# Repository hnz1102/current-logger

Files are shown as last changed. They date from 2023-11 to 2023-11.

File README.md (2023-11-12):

<div align="center">
  <h1><code>Voltage-Current Logger</code></h1>
  <p>
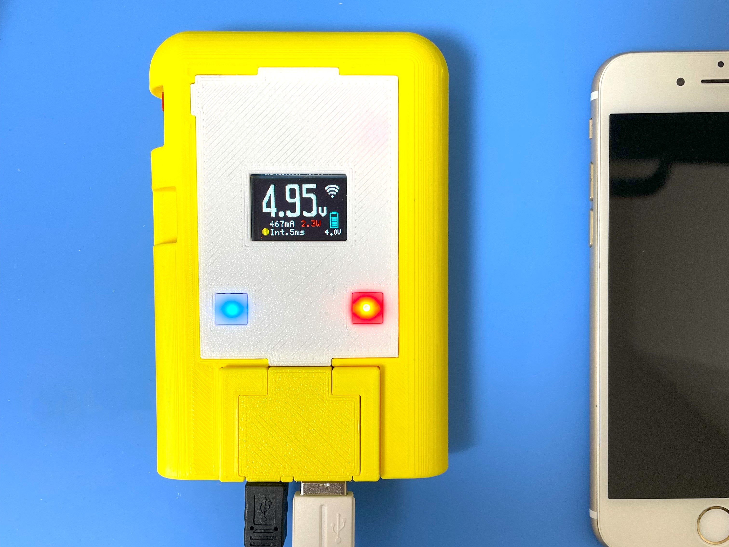
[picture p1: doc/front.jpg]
    
  </p>
</div>

# Voltage-Current Logger - High-resolution digital power monitor and logger

This tool provides a logging function that gets data on voltage, current and power consumption. Voltage input range is from 0 to 85V, Maximum current input is 15A. 

# Feature

**High-resolution** - By using Texas Instruments INA228 IC - 20-bit delta-sigma ADC, It can be got measurement data with 195.uV Bus voltage and 163.84mV Shunt voltage. 

**Microcontroller on board** - No need for a client PC when you are measuring. Directly send to the server. 

**Transfer measurement data via WiFi** - This Logger can transfer data to Linux PC via WiFi network and you can see the dashboard graph in influxDB.

**Battery Powered** - Using LiPo battery. It can run for 24-48 hours.

**Multiple Adopter** - This Logger can be changed 4 type adopters (USB-Type-C-Type-C, USB-Type-A-mini Type-B, JST-PH-Connector for Battery, 3P-Terminal)  

# How to use the Logger
This logger has four types of adapters, and by changing them, it is possible to measure the usage voltage, current, and power consumption of various devices"
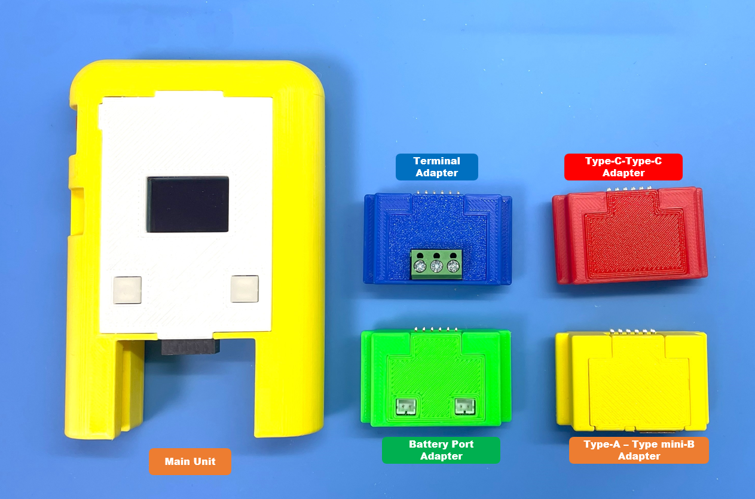
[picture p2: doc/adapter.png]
adapter


* Red Adapter - To measure the voltage and current from USB Type-C Power Adapter to Type-C Power Input Device(PCs, etc.)

* Yellow Adapter - To measure the voltage and current from USB Type mini-B port to USB Type-A output port.

* Green Adapter - To measure the voltage and current between JST-PH connector. (Batteries, etc.)

* Blue Adapter - To measure the voltage and current some cabling type.

For example, if you want to measure the voltage of USB-Type-C power, set the red adopter into the slot. If the power supply does not work, you can try to insert one of the connected Type-C connections in the opposite side of the back. Because a Type-C cable has two sides.
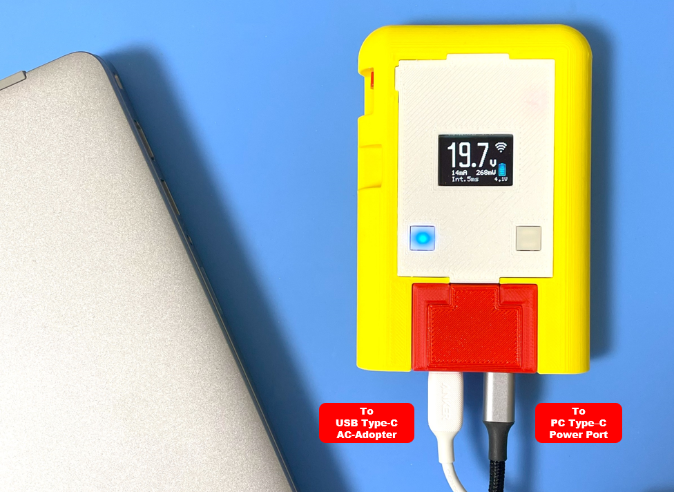
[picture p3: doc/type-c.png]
type-c adopter


The Blue Adapter has 3 pins screw terminal. To measure voltage and current, connect to the following the schematic. 

DO NOT CONNECT WITH OPPOSITE POLARITY. IF CONNECTED, THE ADC IC IS WILL BE DAMAGED.

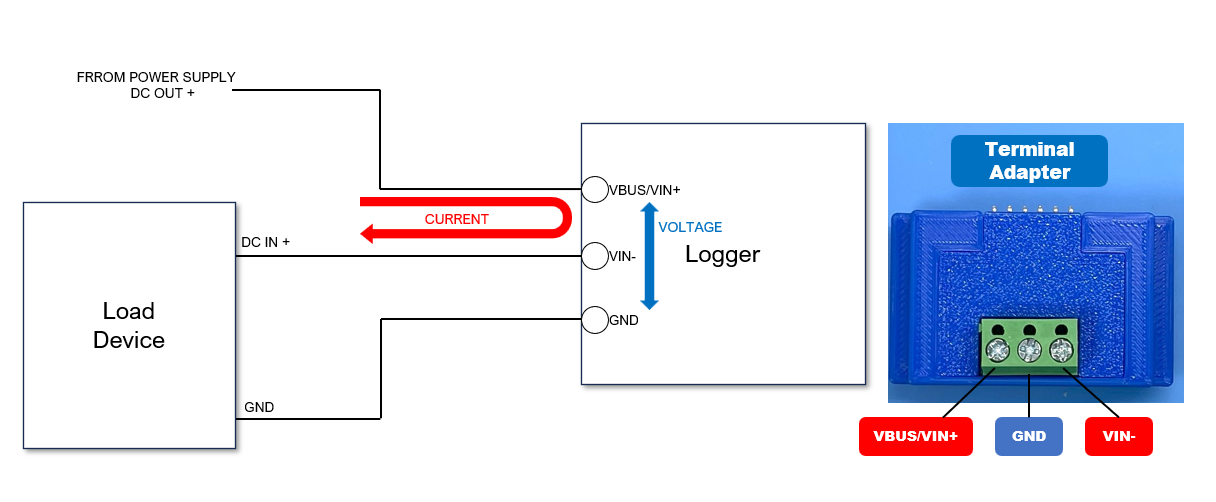
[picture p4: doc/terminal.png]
current


The measurement interval time can be selected from 5 ms to 1 sec. When the logger is powered on, the interval time is 5 ms, then pressing the INT button will set the interval to 10, 50, 100, 500ms, or 1 sec.
Push the START button, then the logger starts to send to the server voltage, current and power consumption data.

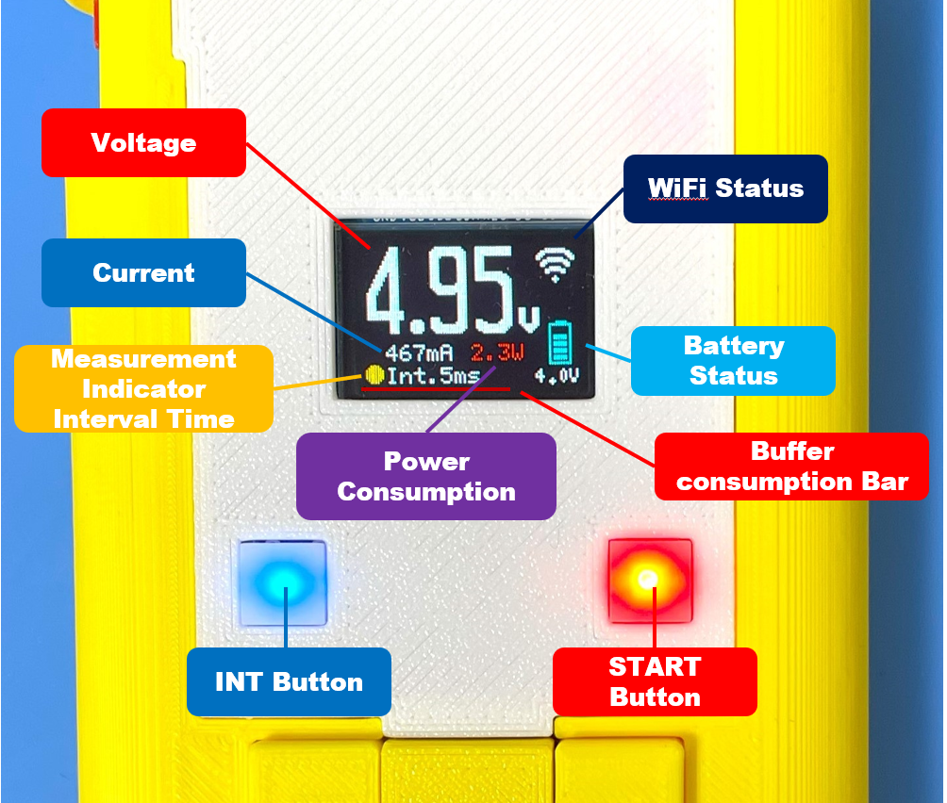
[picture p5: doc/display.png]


A display can show you the current voltage, current, power consumption, battery voltage, buffer consumption, and WiFi connection status.
If the WiFi Access Point cannot establish a connection, the display will not show WiFi mark. If voltage is measured while the WiFi is not connected, the data is stored in the logger's internal memory buffer. The buffer that is not being sent to the server is indicated by a red bar line on the display. When the buffer is full (the line reaches the right edge of the display), the measurement stops automatically. Then, when the WiFi is connected and transmitted to the server, the buffer line shrinks to the left. If the buffer is full and the measurement is stopped, pressing the Start button again discards the measurement data being held and starts the measurement again.

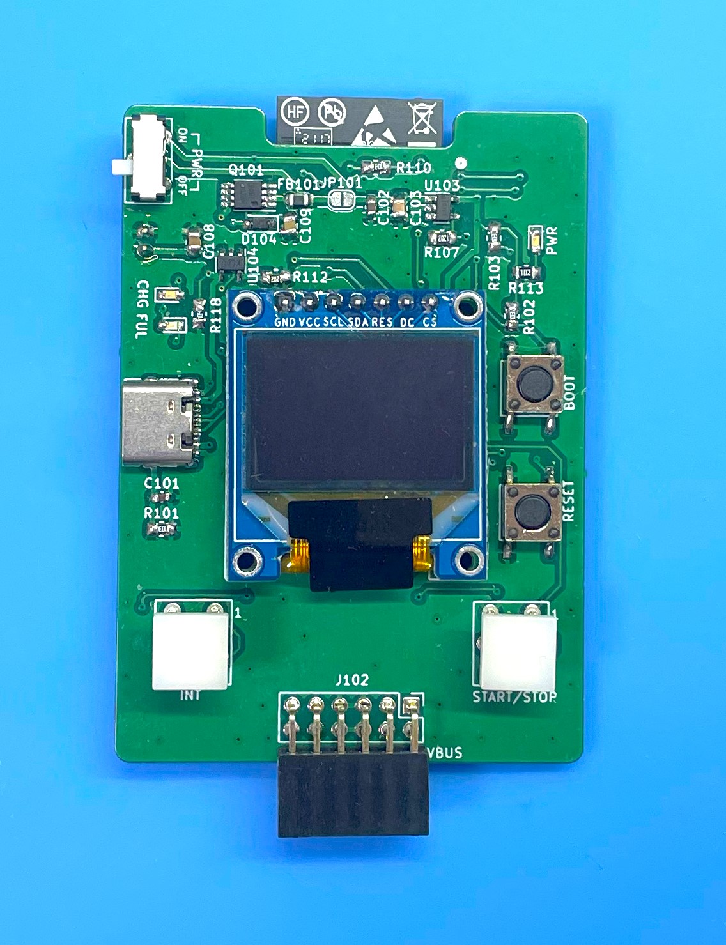
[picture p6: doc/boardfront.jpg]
board


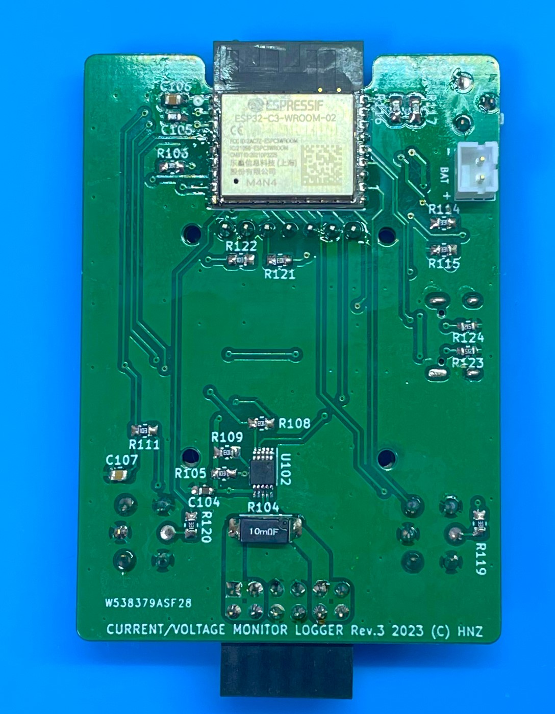
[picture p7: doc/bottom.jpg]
board bottom


If you send data to the server, You can see the realtime data using Dashboard by [InfluxDB](https://www.influxdata.com/influxdb/).

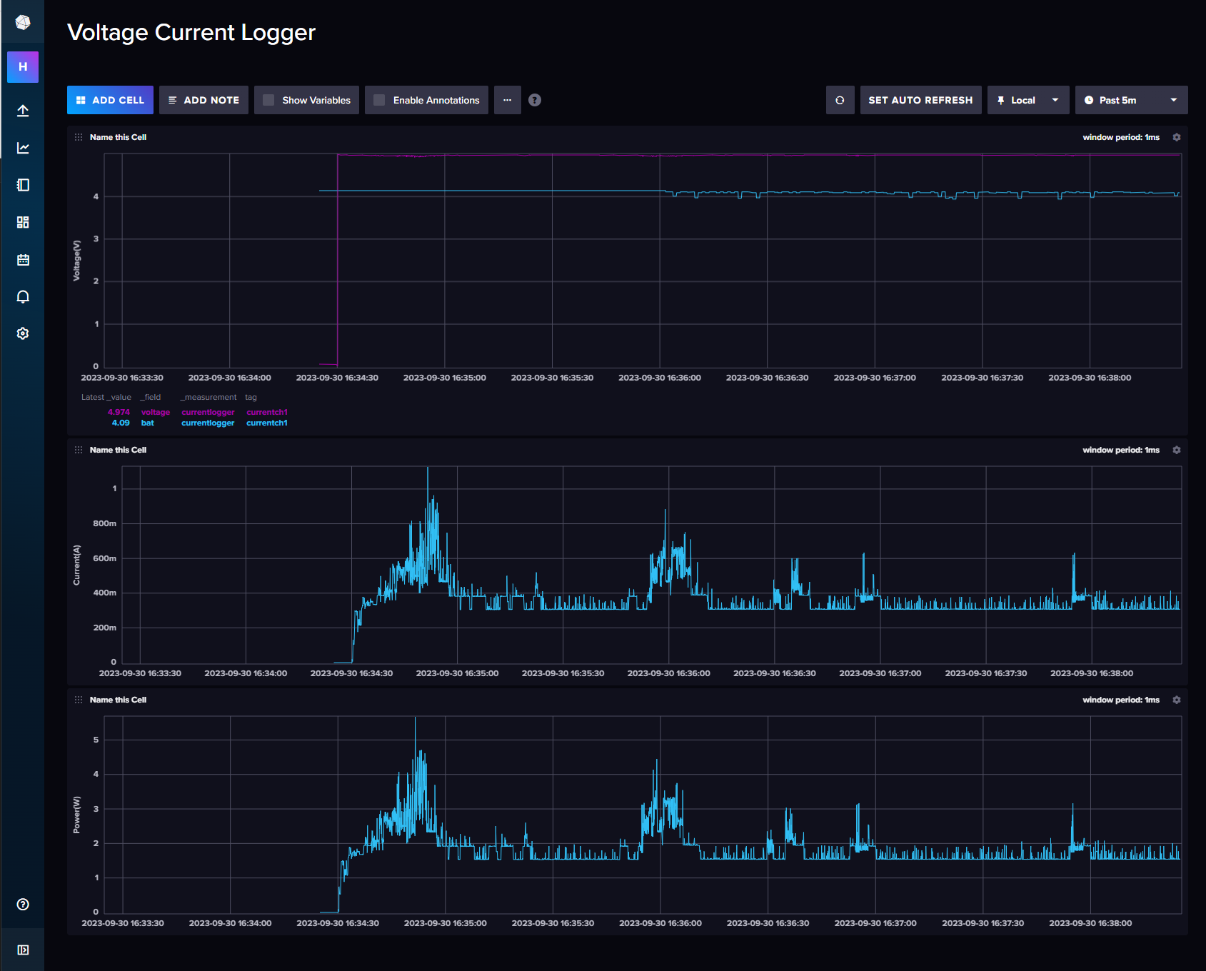
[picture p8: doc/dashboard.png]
dashboard


After the measure, to stop logging, push the START button again.

To charge a battery, just connect to a USB Type-C port from the bus-powered USB port. During the charge, the CHG LED is RED ON. After the charging is full, the FUL LED is GREEN ON. And the charging will be stopped automatically. But, 

DO NOT CONTINUE THE CHARGE IF THE BATTERY IS FULL FOR A LONG TIME. 

# How to build from code and Install to the unit.

Using Ubuntu 22.04.03 LTS

1. Install Rust Compiler
```bash
$ sudo apt -y install git python3 python3-pip gcc build-essential curl pkg-config libudev-dev libtinfo5 clang libclang-dev llvm-dev udev
$ curl --proto '=https' --tlsv1.2 -sSf https://sh.rustup.rs | sh
select No.1
$ source "$HOME/.cargo/env"
```

2. Install toolchain for ESP32-C3
```bash
$ cargo install ldproxy
$ cargo install espup
$ rustup toolchain install nightly --component rust-src
$ rustup target add riscv32imc-unknown-none-elf
$ cargo install cargo-espflash
```

3. Add UDEV rules
```bash
$ sudo sh -c 'echo "SUBSYSTEMS==\"usb\", ATTRS{idVendor}==\"303a\", ATTRS{idProduct}==\"1001\", MODE=\"0666\"" > /etc/udev/rules.d/99-esp32.rules'
$ sudo udevadm control --reload-rules
$ sudo udevadm trigger
```

4. Download Current-Logger code
```bash
$ git clone https://github.com/hnz1102/current-logger.git
$ cd current-logger/src/current-logger
``` 
5. Setting WiFi SSID, Password, and InfluxDB server IP address.
```bash
src\current-logger\cfg.toml

[currentlogger]
wifi_ssid = "<your-AP-ssid>"     # Set your AP ssid.
wifi_psk = "<your-AP-Password>"  # Set password for ssid
http_server = "<PC address>:3001" # Set IP address and port. port should be 3001.
```

6. Connecting the board and Set device and set toolchain.
```bash
Connecting the current-Logger by USB to this build code PC. Then, 
$ cargo espflash board-info
select /dev/ttyACM0
Chip type:         esp32c3 (revision v0.4)
Crystal frequency: 40MHz
Flash size:        4MB
Features:          WiFi, BLE
MAC address:       xx:xx:xx:xx:xx:xx

$ rustup component add rust-src --toolchain nightly-2023-06-10-x86_64-unknown-linux-gnu
```

7. Build code and writing flash
```bash
$ cargo espflash flash --release --monitor
App/part. size:    964,240/3,145,728 bytes, 30.23%
[00:00:00] [========================================]      12/12      0x0                                                                       
[00:00:00] [========================================]       1/1       0x8000                                                                    
[00:00:11] [========================================]     546/546     0x10000                                                                   [2023-11-11T10:17:05Z INFO ] Flashing has completed!

And automaticaly boot!
```
# How to Install the influxDB and Agent

1. Download [influxDB](https://docs.influxdata.com/influxdb/v2.7/install/?t=Linux) and Install.
```bash
$ wget https://dl.influxdata.com/influxdb/releases/influxdb2-2.7.0-amd64.deb
$ sudo dpkg -i influxdb2-2.7.0-amd64.deb
$ sudo service influxdb start
```

2. Configure the influxDB

```
Connect to the 'http://<influxDB installed PC Address>:8086'
```
Click `GET STARTED` and set `Username`, `Password`, `Initial Organization Name`, and `Initial Bucket Name`
|Term|Value|
|---|---|
|Username|Set login username as influxDB administrator web console|
|Password|Set login password as influxDB administrator web console|
|Initial Organization Name| Organization Name ex. ORG|
|Initail Bucket Name| LOGGER |

After set them, click `CONTINUE`.

3. Copy the operator API token.

You can see the operator API token on the browser. YOU WON'T BE ABLE TO SEE IT AGAIN!
If you want to get new API token, click `API Tokens` menu form `Sources` Icon, then click `GENERATE API TOKEN` and select `All access token`, click `Save`.
You can see a new API token and get it.
After copy the token, click `CONFIGURE LATER`.

4. Import the Dashboard Template.

Click the `Dashboard` icon, and select `Import Dashboard` from the `CREATE DASHBOARD` menu.

Drop the `src/server/voltage_current_logger.json` file to `Drop a file here`, then click `IMPORT JSON AS DASHBOARD`.

You can see the `Voltage Current Logger Dashboard` pannel on the Dashboards page.

Click this panel, and You can see the Voltage-Current-Logger Dashboard.

If you want to customize the dashboard design, click configure mark. You can change the graph design.

5. Install the Agent.

Current-Logger can't directly send data to influxDB API since ESP32-C3 has not TSL software stack. This agent program is responsible for changing HTTP communication from Current-Logger to HTTPS communication and passing data to the InfluxDB API. This agent is purpose only for a local network because it has no security.

Before install you have to change parameters in main.js.

src/server/main.js
```javascript
const token = "<influxDB API Access Token>"
const url = 'http://<influxDB installed IP address>:8086'
let org = `<YOUR ORGANIZATION NAME: it has to be same the Initial Organization Name>`
let bucket = `LOGGER`
```

Install the agent program.

```bash
$ sudo apt install nodejs npm
$ cd src/server/
$ ./install.sh
```
If it is `Active: active` as shown below, it has started normally.
```
● influxdb-agent-current.service - InfluxDB Agent for Currentlogger
     Loaded: loaded (/lib/systemd/system/influxdb-agent-current.service; enabled; vendor preset: enabled)
     Active: active (running) since Sat 2023-11-11 11:36:02 UTC; 12ms ago
    Process: 6883 ExecStart=/var/lib/currentlogger/influxdb-agent-start.sh (code=exited, status=0/SUCCESS)
   Main PID: 6884 (node)
      Tasks: 1 (limit: 19009)
     Memory: 1.5M
        CPU: 10ms
     CGroup: /system.slice/influxdb-agent-current.service
             └─6884 /usr/bin/node /var/lib/currentlogger/main.js
```

6. Start Current-Logger Logging and Send Data.

Push the START button. Logging data will be sent to the influxDB. You can see the data on the dashboard.

## Schematic, PCB Gabar and Container 3D Data

There is a Schematic data in hardware directory include 3D printing data. 

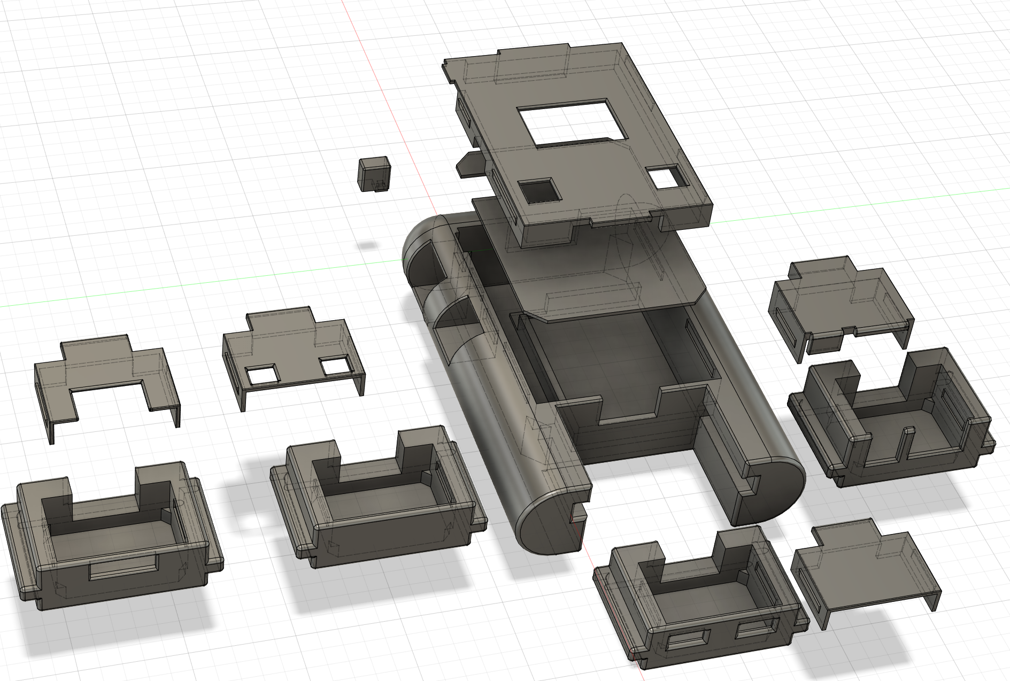
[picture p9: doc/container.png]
Container


## LICENSE
This source code is licensed under MIT. Other Hardware Schematic documents are licensed under CC-BY-SA V4.0.

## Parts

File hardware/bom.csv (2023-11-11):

Reference | Value | Footprint | Datasheet | distributor | Qty
C101,C102,C104,C105 | 0.1uF | Capacitor_SMD:C_0603_1608Metric_Pad1.08x0.95mm_HandSolder | ~ | https://www.digikey.com/en/products/detail/yageo/CC0603ZRY5V9BB104/2103081 | 4
C103, C106 | 10uF | Capacitor_SMD:C_0805_2012Metric_Pad1.18x1.45mm_HandSolder | ~ | https://www.digikey.com/en/products/detail/murata-electronics/GRM21BR61C106KE15K/2546903 | 2
C107, C109 | 1uF | Capacitor_SMD:C_0805_2012Metric | ~ | https://www.digikey.com/en/products/detail/yageo/CC0805ZRY5V7BB105/2833622 | 2
C108 | 4.7uF | Capacitor_SMD:C_0805_2012Metric_Pad1.18x1.45mm_HandSolder | ~ | https://www.digikey.com/en/products/detail/yageo/CC0805ZRY5V6BB475/2103109 | 1
D101, D102 | LED RED | LED_SMD:LED_0603_1608Metric_Pad1.05x0.95mm_HandSolder | ~ | https://www.digikey.com/en/products/detail/harvatek-corporation/B1931URO-20D000114U1930/15910603 | 2
D103 | LED GREEN | LED_SMD:LED_0603_1608Metric_Pad1.05x0.95mm_HandSolder | ~ | https://www.digikey.com/en/products/detail/harvatek-corporation/B1931NG-20D001114U1930/15861262 | 1
D104 | NSR0340HT1G | Diode_SMD:D_SOD-323_HandSoldering | https://www.onsemi.com/pub/Collateral/NSR0340H-D.PDF | https://www.digikey.com/en/products/detail/onsemi/NSR0340HT1G/1981491 | 1
FB101 | MH2029-601Y | Inductor_SMD:L_0805_2012Metric | ~ | https://www.digikey.com/en/products/detail/bourns-inc/MH2029-601Y/3741762 | 1
J101, J201, J202 | USB4105-GF-A | Library:USB_C_5077CR-16-SMC2-BK-TR | https://www.usb.org/sites/default/files/documents/usb_type-c.zip | https://www.digikey.com/en/products/detail/gct/USB4105-GF-A/11198441 | 3
J102, J203, J206, J208, J211 | PINOUT | Connector_PinHeader_2.54mm:PinHeader_2x06_P2.54mm_Vertical | ~ |  | 5
J104 | LiPo BATTERY | Connector_JST:JST_PH_B2B-PH-K_1x02_P2.00mm_Vertical | ~ | https://www.digikey.com/en/products/detail/jst-sales-america-inc/B2B-PH-K-S/926611 | 1
J204 | USB_B_Mini | Library:usb mini B connector c2235 dim 2 | ~ | https://akizukidenshi.com/catalog/g/gC-02235/ | 1
J205 | USB_A | Library:USB_A_5075AR-04 | ~ | https://akizukidenshi.com/catalog/g/gC-00160/ | 1
J207 | Screw_Terminal_01x03 | Library:TB112-2-2-3-E-1 Terminal Block | ~ | https://akizukidenshi.com/catalog/g/gP-01310/ | 1
J209 | BATTERY OUT JST_PH | Connector_JST:JST_PH_B2B-PH-K_1x02_P2.00mm_Vertical | ~ | https://www.digikey.com/en/products/detail/jst-sales-america-inc/B2B-PH-K-S/926611 | 1
J210 | BATTERY IN JST_PH | Connector_JST:JST_PH_B2B-PH-K_1x02_P2.00mm_Vertical | ~ | https://www.digikey.com/en/products/detail/jst-sales-america-inc/B2B-PH-K-S/926611 | 1
JP101 | SolderJumper_2_Open | Jumper:SolderJumper-2_P1.3mm_Open_RoundedPad1.0x1.5mm | ~ |  | 1
Q101 | IRF7606TRPBF | Package_SO:MSOP-8_3x3mm_P0.65mm | http://www.irf.com/product-info/datasheets/data/irf7606pbf.pdf | https://www.digikey.com/en/products/detail/infineon-technologies/IRF7606TRPBF/856652 | 1
R101-R103, R105, R108-R111, R121, R122 | 10K | Resistor_SMD:R_0805_2012Metric_Pad1.20x1.40mm_HandSolder | ~ | https://www.digikey.jp/en/products/detail/yageo/RC0603JR-1010KL/13694233 | 10
R104 | 10m | Library:R_10mOHM | ~ | https://akizukidenshi.com/catalog/g/gP-01886/ | 1
R106, R116, R117 | 20K 1% | Resistor_SMD:R_0805_2012Metric_Pad1.20x1.40mm_HandSolder | ~ | https://www.digikey.jp/en/products/detail/yageo/RC0603FR-0720KL/727040 | 3
R107 | 12K 1% | Resistor_SMD:R_0805_2012Metric_Pad1.20x1.40mm_HandSolder | ~ | https://www.digikey.com/en/products/detail/yageo/RC0603FR-0712KL/726913 | 1
R112 | 2K | Resistor_SMD:R_0805_2012Metric_Pad1.20x1.40mm_HandSolder | ~ | https://www.digikey.com/en/products/detail/yageo/RC0603JR-072KL/726726 | 1
R113 | 1K | Resistor_SMD:R_0805_2012Metric_Pad1.20x1.40mm_HandSolder | ~ | https://www.digikey.com/en/products/detail/yageo/RC0603FR-071KL/726843 | 1
R114, R115, R119, R120 | 330 | Resistor_SMD:R_0805_2012Metric_Pad1.20x1.40mm_HandSolder | ~ | https://www.digikey.com/en/products/detail/yageo/RC0603JR-13330RL/14286483 | 4
R118 | 100K | Resistor_SMD:R_0805_2012Metric_Pad1.20x1.40mm_HandSolder | ~ | https://www.digikey.com/en/products/detail/yageo/RC0603JR-07100KL/726698 | 1
R123, R124 | 5.1K | Resistor_SMD:R_0603_1608Metric | ~ | https://www.digikey.com/en/products/detail/yageo/RC0603JR-075K1L/726796 | 2
SW101, SW102 | TS-06104 | Library:TS-06104 |  | https://akizukidenshi.com/catalog/g/gP-15969/ | 2
SW103 | SW_Push_LED_BLUE | Library:LS601-CU_CAP | ~ | https://akizukidenshi.com/catalog/g/gP-13871/ | 1
SW104 | SW_Push_LED_RED | Library:LS601-CU_CAP | ~ | https://akizukidenshi.com/catalog/g/gP-13870/ | 1
SW105 | SLIDE_SW | Library:SLIDE_SW_IS1235-G | ~ | https://akizukidenshi.com/catalog/g/gP-15368/ | 1
U101 | ESP32-C3-WROOM-02-N4 | Library:IC18_ESP32-C3-WROOM-02-N4_EXP | ESP32-C3-WROOM-02-N4 | https://www.digikey.com/en/products/detail/espressif-systems/ESP32-C3-WROOM-02-N4/14553031 | 1
U102 | INA228 | Package_SO:VSSOP-10_3x3mm_P0.5mm | http://www.ti.com/lit/ds/symlink/ina226.pdf | https://www.digikey.com/en/products/detail/texas-instruments/INA228AIDGSR/13691042 | 1
U103 | SPX3819M5-L | Package_TO_SOT_SMD:SOT-23-5 | https://www.exar.com/content/document.ashx?id=22106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 | https://www.digikey.com/en/products/detail/maxlinear-inc/SPX3819M5-L-TR/2472388 | 1
U104 | MCP73831-2-OT | Package_TO_SOT_SMD:SOT-23-5 | http://ww1.microchip.com/downloads/en/DeviceDoc/20001984g.pdf | https://www.digikey.com/en/products/detail/microchip-technology/MCP73831T-2ACI-OT/964301 | 1
U105 | SSD1331_DISPLAY | Library:OLED SSD1331 SPI DISPLAY |  | https://akizukidenshi.com/catalog/g/gP-14435/ | 1

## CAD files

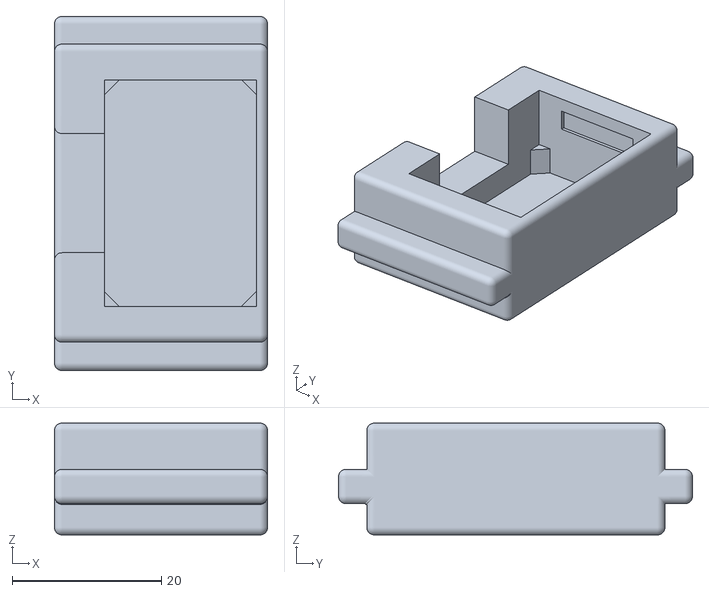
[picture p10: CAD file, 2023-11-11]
hardware/stl/Adoptor-Battery-v10.stl
28.6 x 47.5 x 15.0

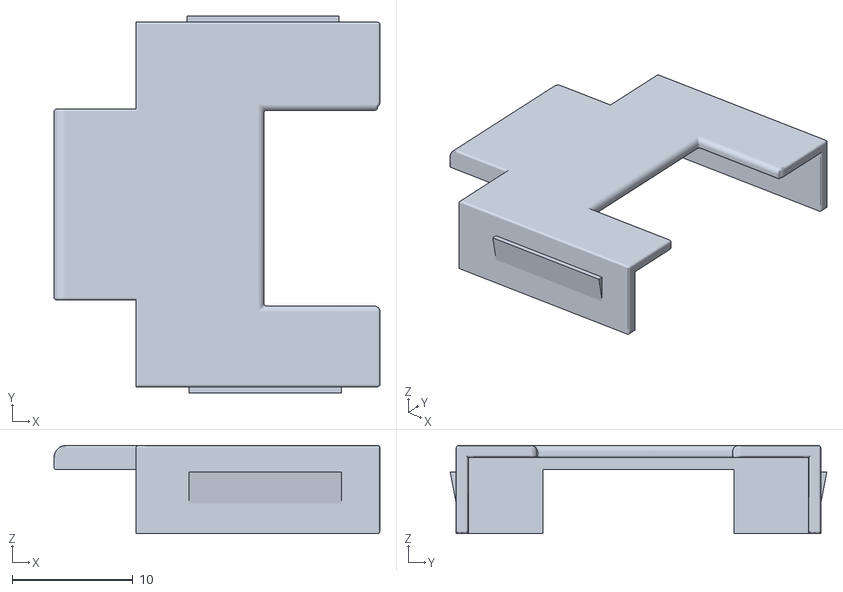
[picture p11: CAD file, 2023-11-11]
hardware/stl/Adopter-Terminal-Upper-v12.stl
27.0 x 31.2 x 7.30

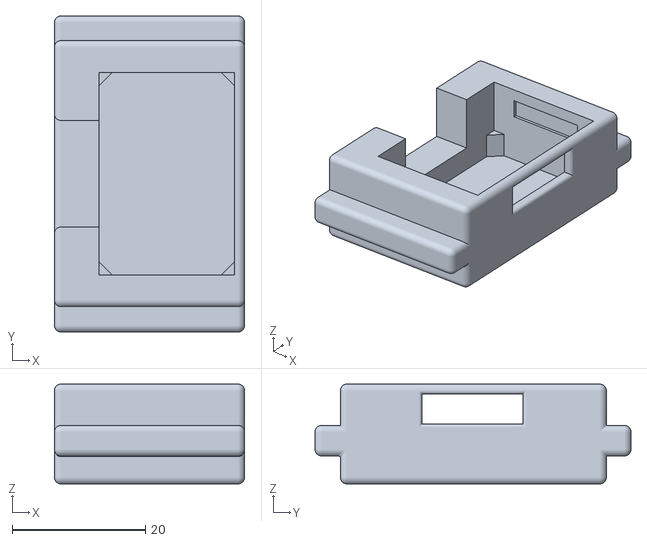
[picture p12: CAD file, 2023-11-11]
hardware/stl/Adoptor-Terminal-v10.stl
28.6 x 47.5 x 15.0

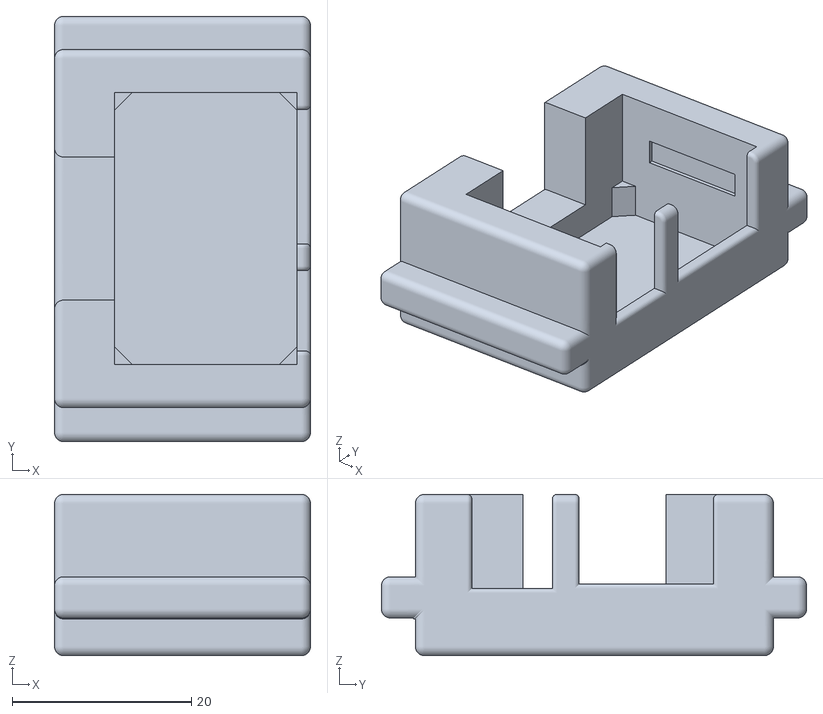
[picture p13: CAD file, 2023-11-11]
hardware/stl/Adoptor-TypeAB-v10.stl
28.6 x 47.5 x 18.0

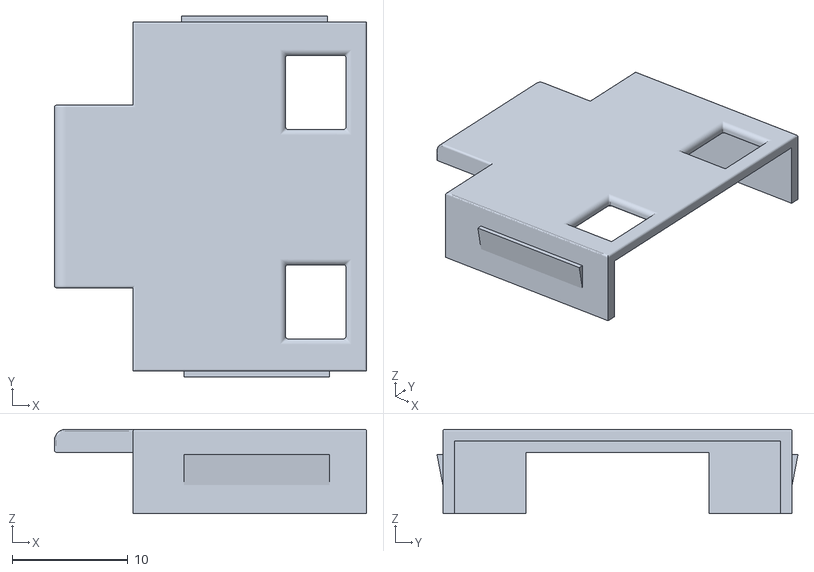
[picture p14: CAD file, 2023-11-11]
hardware/stl/Adopter-Battery-Upper-v10.stl
27.0 x 31.2 x 7.30

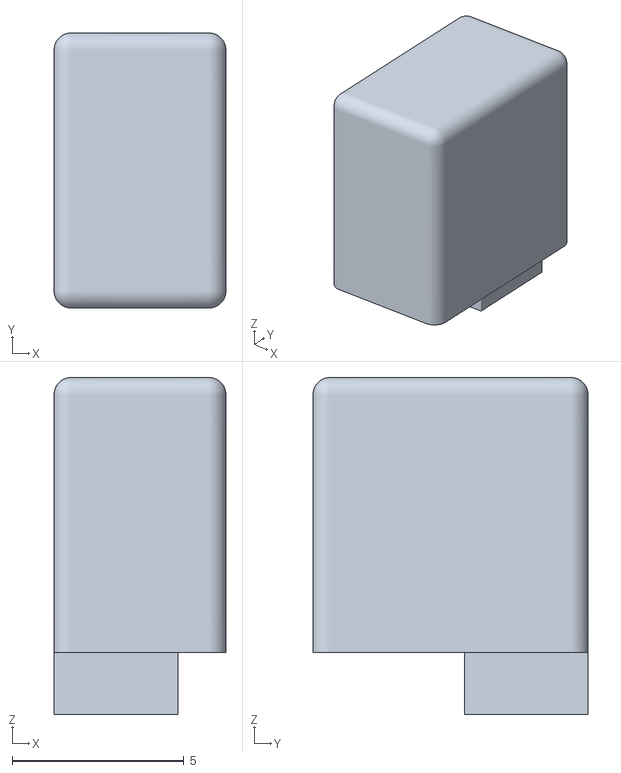
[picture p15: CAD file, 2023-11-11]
hardware/stl/SW-CAP-v15.stl
5.00 x 8.00 x 9.80

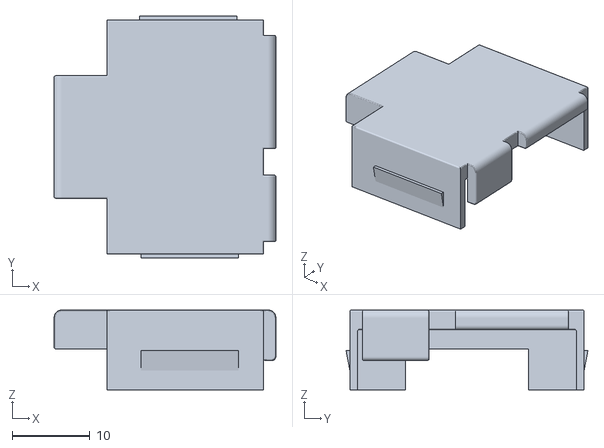
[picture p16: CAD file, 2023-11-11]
hardware/stl/Adopter-TypeAB-Upper-v10.stl
28.6 x 31.2 x 10.3

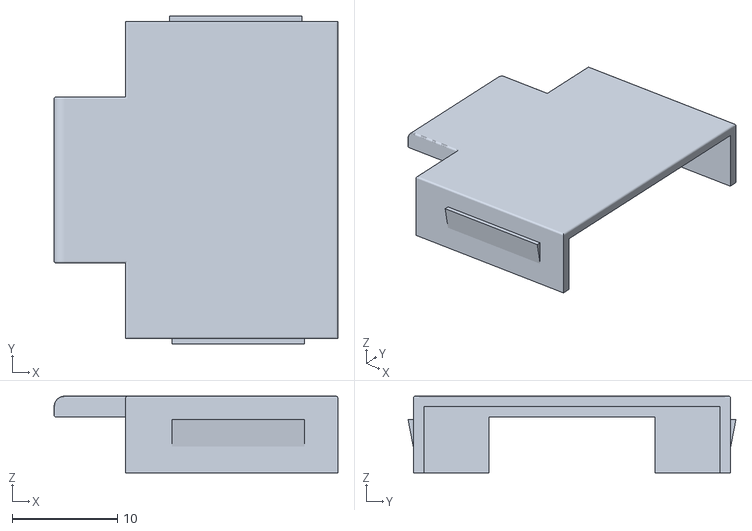
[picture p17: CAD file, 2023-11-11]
hardware/stl/Adopter-TypeC-Upper-v18.stl
27.0 x 31.2 x 7.30

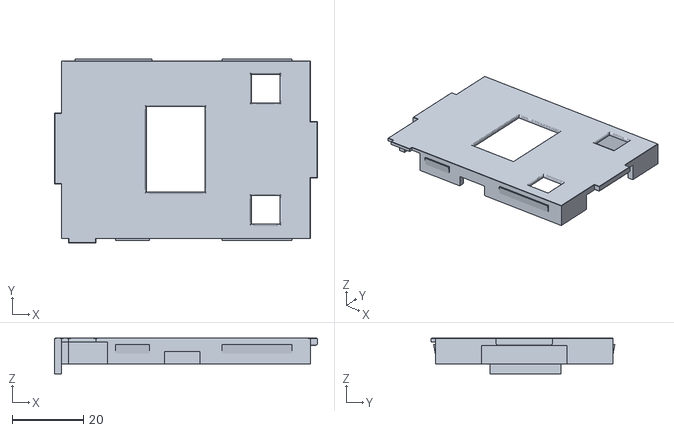
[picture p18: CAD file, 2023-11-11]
hardware/stl/upper-v10.stl
73.9 x 51.7 x 10.0

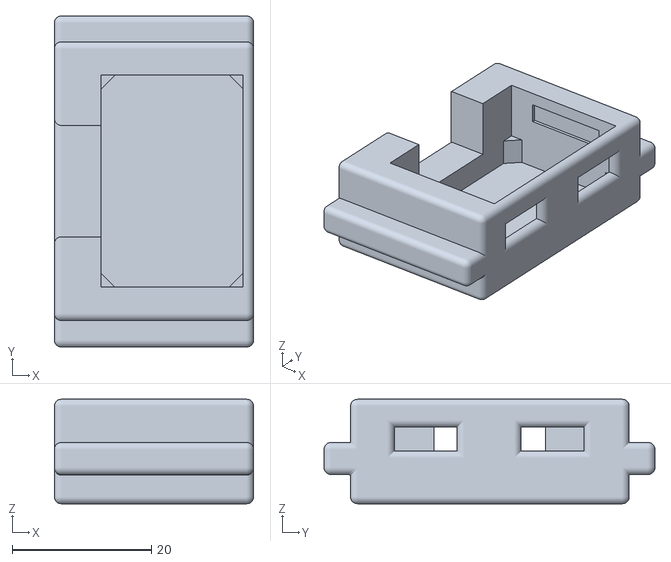
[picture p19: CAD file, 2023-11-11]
hardware/stl/Adoptor-TypeC-v10.stl
28.6 x 47.5 x 15.0

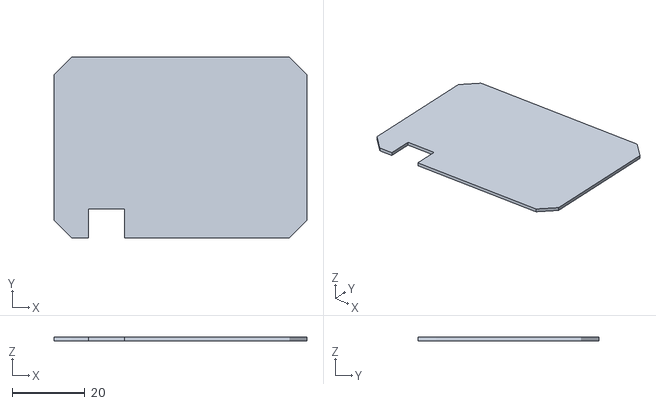
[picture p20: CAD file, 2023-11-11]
hardware/stl/separator-v11.stl
69.8 x 49.8 x 1.00

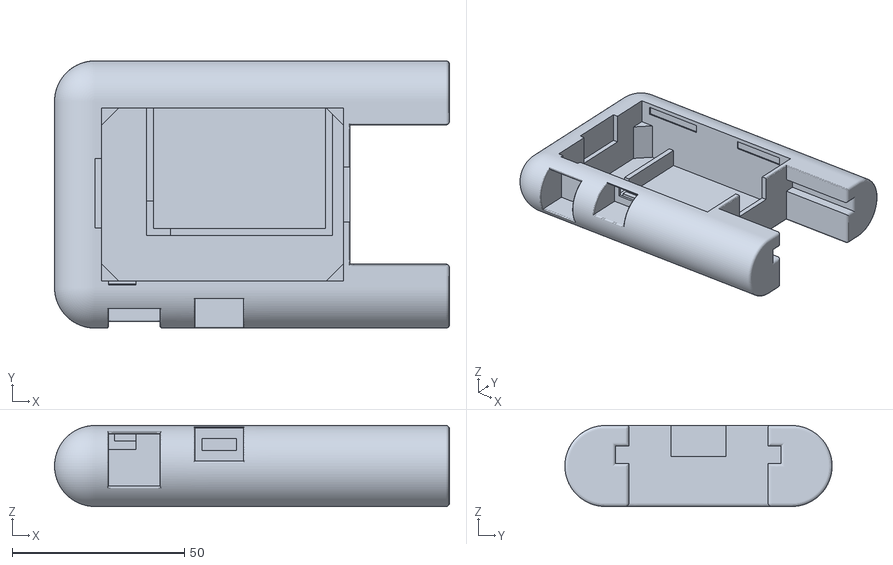
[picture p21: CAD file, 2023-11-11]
hardware/stl/Bottom-v17.stl
114.6 x 77.5 x 23.5

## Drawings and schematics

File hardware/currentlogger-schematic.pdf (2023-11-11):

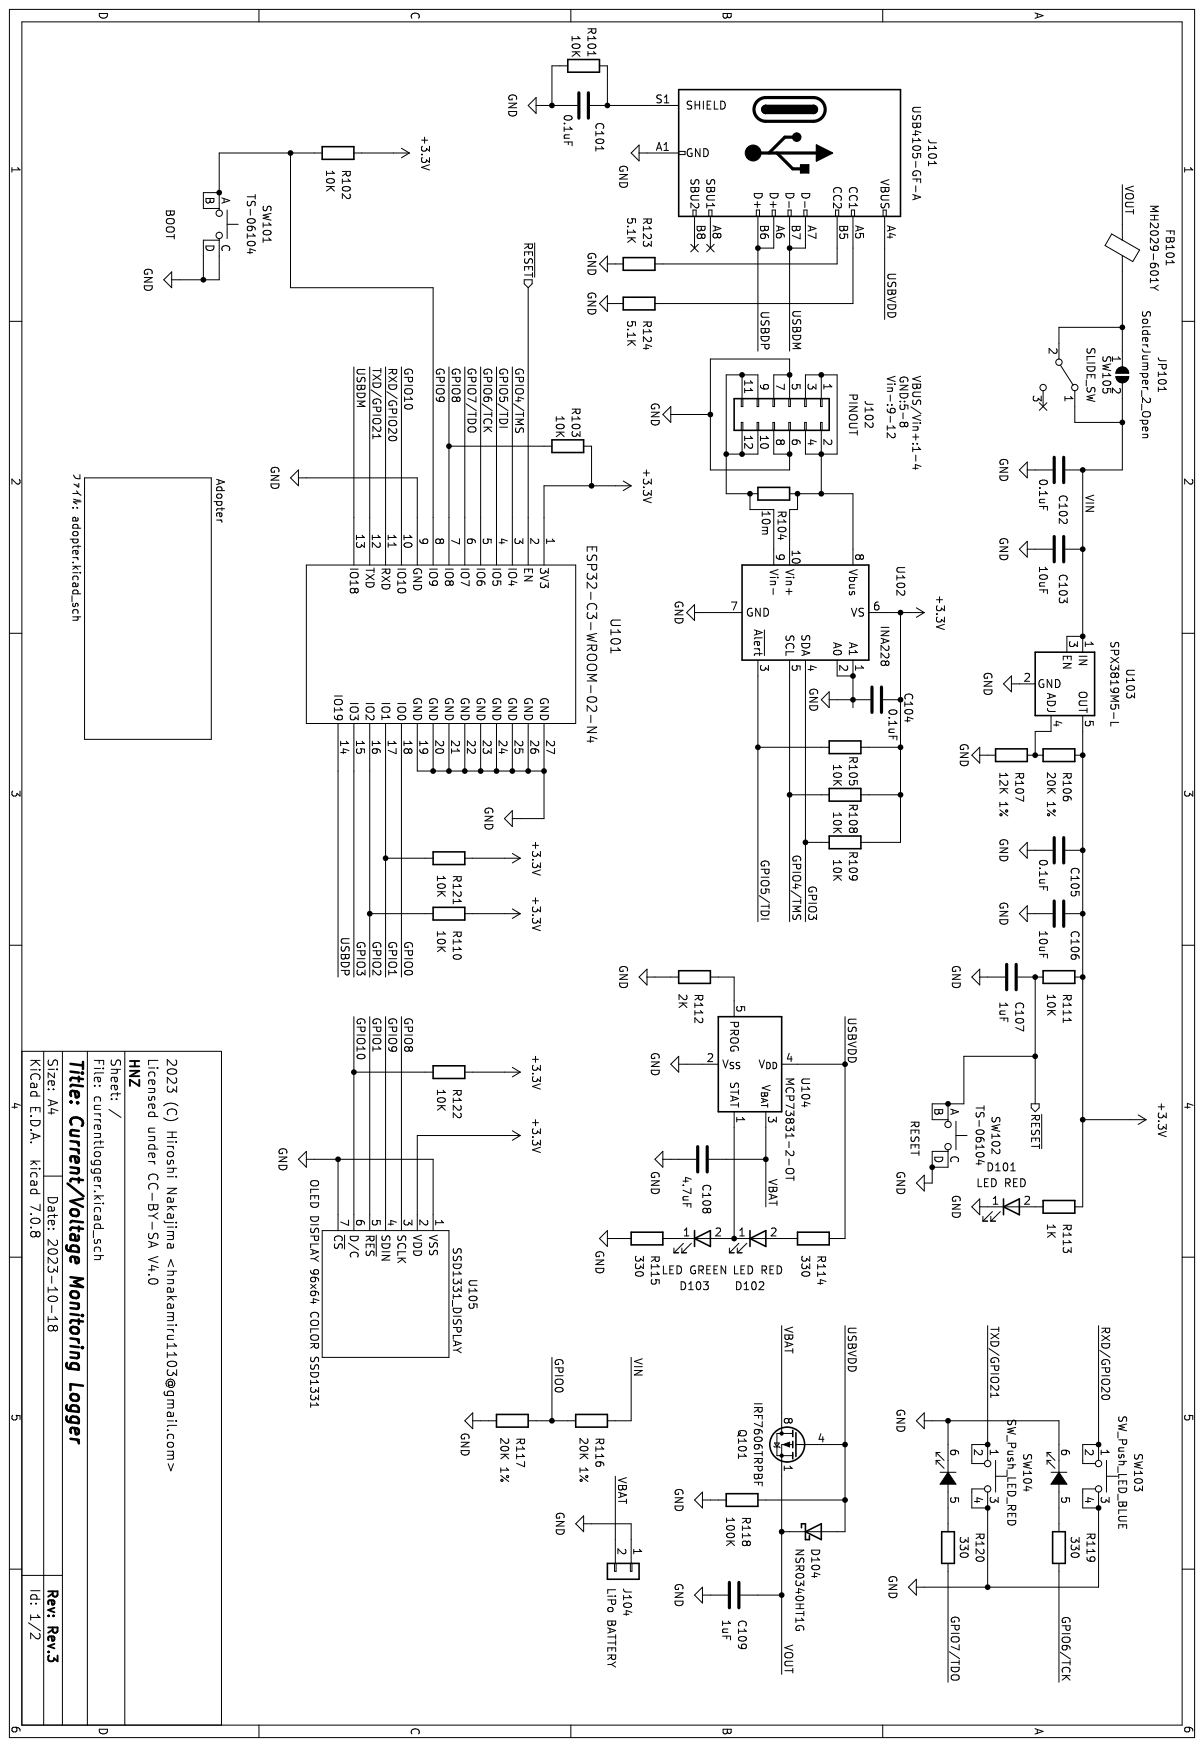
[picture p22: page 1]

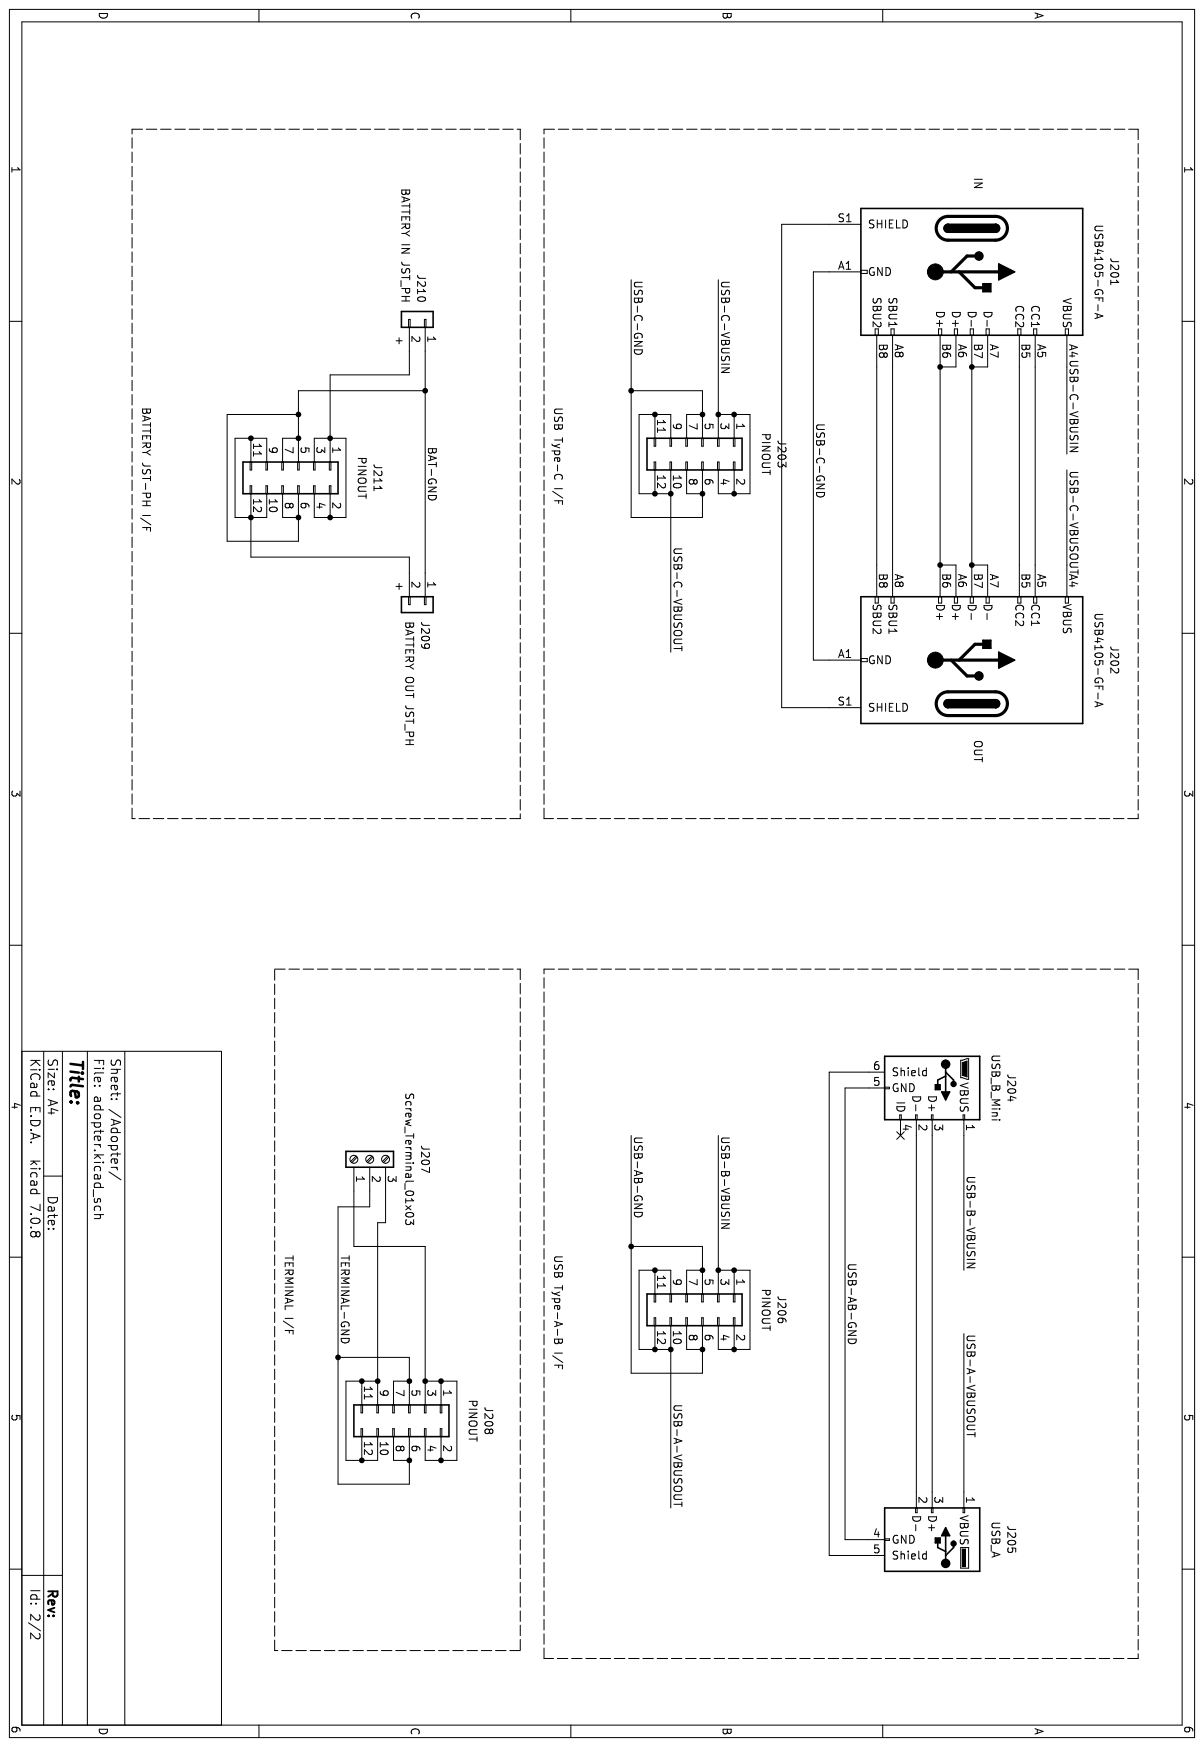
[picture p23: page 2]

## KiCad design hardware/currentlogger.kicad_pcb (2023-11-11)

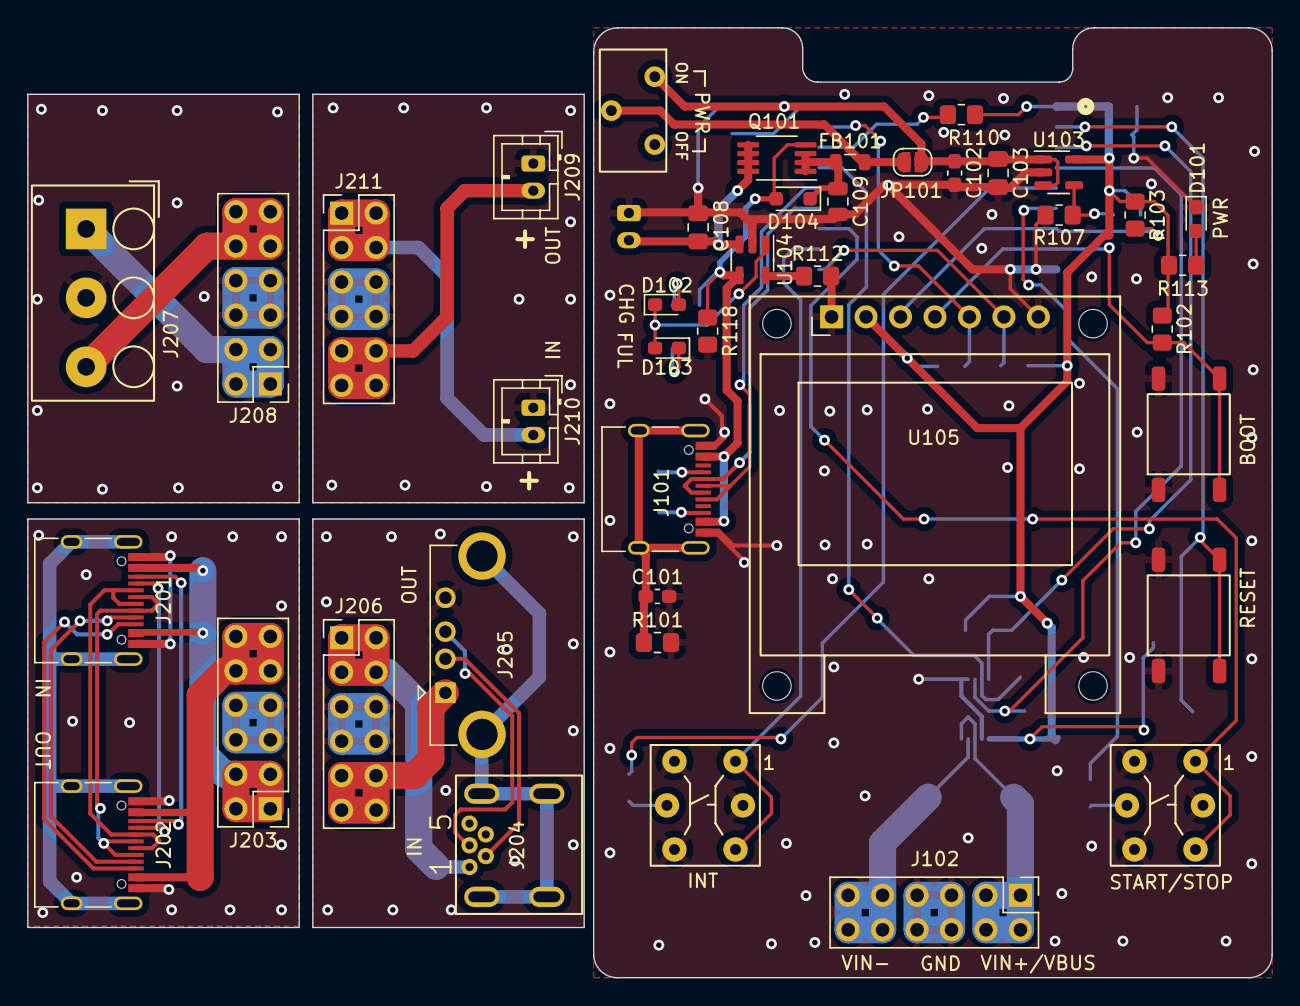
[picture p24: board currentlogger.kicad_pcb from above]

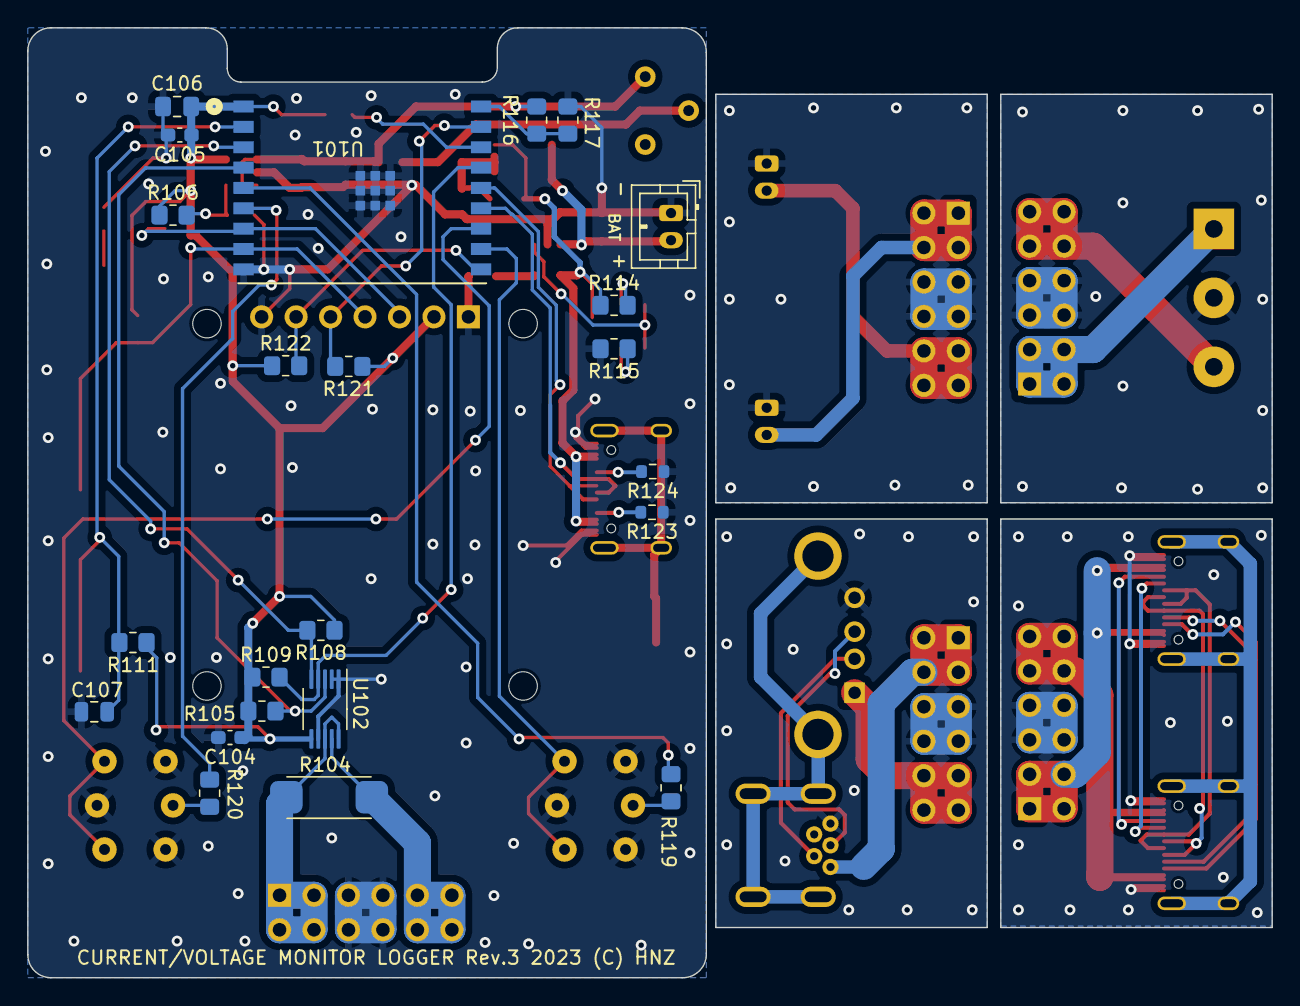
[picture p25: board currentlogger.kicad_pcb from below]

Board: 2 copper layers, 91.7 x 70.0 mm, 64 parts (23 on the bottom side), 58 nets.

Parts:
C101, C102, C104, C105: 0.1uF; C_0603_1608Metric_Pad1.08x0.95mm_HandSolder
C103, C106: 10uF; C_0805_2012Metric_Pad1.18x1.45mm_HandSolder
C107, C109: 1uF; C_0805_2012Metric
C108: 4.7uF; C_0805_2012Metric_Pad1.18x1.45mm_HandSolder
D101, D102: LED RED; LED_0603_1608Metric_Pad1.05x0.95mm_HandSolder
D103: LED GREEN; LED_0603_1608Metric_Pad1.05x0.95mm_HandSolder
D104: NSR0340HT1G; D_SOD-323_HandSoldering
FB101: BK2125HS601-T; L_0805_2012Metric
J101, J201, J202: USB_C_Receptacle_USB2.0_5077CR; USB_C_5077CR-16-SMC2-BK-TR
J102, J203, J206, J208, J211: PINOUT; PinHeader_2x06_P2.54mm_Vertical
J104: LiPo BATTERY; JST_PH_B2B-PH-K_1x02_P2.00mm_Vertical
J204: USB_B_Mini; usb mini B connector c2235 dim 2
J205: USB_A; USB_A_5075AR-04
J207: Screw_Terminal_01x03; TB112-2-2-3-E-1 Terminal Block
J209: BATTERY OUT JST_PH; JST_PH_B2B-PH-K_1x02_P2.00mm_Vertical
J210: BATTERY IN JST_PH; JST_PH_B2B-PH-K_1x02_P2.00mm_Vertical
JP101: SolderJumper_2_Open; SolderJumper-2_P1.3mm_Open_RoundedPad1.0x1.5mm
Q101: IRF7606PBF; MSOP-8_3x3mm_P0.65mm
R101, R102, R103, R105, R108, R109, R110, R111, R121, R122: 10K; R_0805_2012Metric_Pad1.20x1.40mm_HandSolder
R104: 10m; R_10mOHM
R106, R116, R117: 20K 1%; R_0805_2012Metric_Pad1.20x1.40mm_HandSolder
R107: 12K 1%; R_0805_2012Metric_Pad1.20x1.40mm_HandSolder
R112: 2K; R_0805_2012Metric_Pad1.20x1.40mm_HandSolder
R113: 1K; R_0805_2012Metric_Pad1.20x1.40mm_HandSolder
R114, R115, R119, R120: 330; R_0805_2012Metric_Pad1.20x1.40mm_HandSolder
R118: 100K; R_0805_2012Metric_Pad1.20x1.40mm_HandSolder
R123, R124: 5.1K; R_0603_1608Metric
SW101, SW102: TS-06104
SW103, SW104: SW_Push_LED; LS601-CU_CAP
SW105: SLIDE_SW; SLIDE_SW_IS1235-G
U101: ESP32-C3-WROOM-02-N4; IC18_ESP32-C3-WROOM-02-N4_EXP
U102: INA228; VSSOP-10_3x3mm_P0.5mm
U103: SPX3819M5-L; SOT-23-5
U104: MCP73831-2-OT; SOT-23-5
U105: SSD1331_DISPLAY; OLED SSD1331 SPI DISPLAY

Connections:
+3.3V: C104.1, C105.1, C106.1, R102.1, R103.1, R105.1, R106.1, R108.1, R109.1, R110.1, R111.1, R113.1, R121.1, R122.1, U101.1 (3V3), U102.6 (VS), U103.5 (OUT), U105.2 (VDD)
/Adopter/BAT-GND: J209.1, J210.1, J211.5, J211.6, J211.7, J211.8
/Adopter/TERMINAL-GND: J207.2, J208.5, J208.6, J208.7, J208.8
/Adopter/USB-A-VBUSOUT: J205.1 (VBUS), J206.9, J206.10, J206.11, J206.12
/Adopter/USB-AB-GND: J204.5 (GND), J205.4 (GND), J206.5, J206.6, J206.7, J206.8
/Adopter/USB-B-VBUSIN: J204.1 (VBUS), J206.1, J206.2, J206.3, J206.4
/Adopter/USB-C-GND: J201.A1 (GND), J201.A12 (GND), J201.B1 (GND), J201.B12 (GND), J202.A1 (GND), J202.A12 (GND), J202.B1 (GND), J202.B12 (GND), J203.5, J203.6, J203.7, J203.8
/Adopter/USB-C-VBUSIN: J201.A4 (VBUS), J201.A9 (VBUS), J201.B4 (VBUS), J201.B9 (VBUS), J203.1, J203.2, J203.3, J203.4
/Adopter/USB-C-VBUSOUT: J202.A4 (VBUS), J202.A9 (VBUS), J202.B4 (VBUS), J202.B9 (VBUS), J203.9, J203.10, J203.11, J203.12
/GPIO0: R116.2, R117.1, U101.18 (IO0)
/GPIO1: R121.2, U101.17 (IO1), U105.5 (~RES)
/GPIO2: R110.2, U101.16 (IO2)
/GPIO3: R109.2, U101.15 (IO3), U102.4 (SDA)
/GPIO4/TMS: R108.2, U101.3 (IO4), U102.5 (SCL)
/GPIO5/TDI: R105.2, U101.4 (IO5), U102.3 (~Alert)
/GPIO6/TCK: R119.2, U101.5 (IO6)
/GPIO7/TDO: R120.2, U101.6 (IO7)
/GPIO8: R103.2, U101.7 (IO8), U105.3 (SCLK)
/GPIO9: R102.2, SW101.A, SW101.B, U101.8 (IO9), U105.4 (SDIN)
/GPIO10: R122.2, U101.10 (IO10), U105.6 (D/C)
/RXD/GPIO20: SW103.1, SW103.2, U101.11 (RXD)
/TXD/GPIO21: SW104.1, SW104.2, U101.12 (TXD)
/USBDM: J101.A7 (D-), J101.B7 (D-), U101.13 (IO18)
/USBDP: J101.A6 (D+), J101.B6 (D+), U101.14 (IO19)
/USBVDD: D104.2 (A), J101.A4 (VBUS), J101.A9 (VBUS), J101.B4 (VBUS), J101.B9 (VBUS), Q101.4 (G), R114.1, R118.1, U104.4 (V_{DD})
/VBAT: C108.1, J104.2, Q101.5 (D), Q101.6 (D), Q101.7 (D), Q101.8 (D), U104.3 (V_{BAT})
/VIN: C102.1, C103.1, JP101.2 (B), R116.1, SW105.1 (A), U103.1 (IN), U103.3 (EN)
/VOUT: C109.1, D104.1 (K), FB101.1, Q101.1 (S), Q101.2 (S), Q101.3 (S)
/~RESET: C107.1, R111.2, SW102.A, SW102.B, U101.2 (EN)
GND: C101.2, C102.2, C103.2, C104.2, C105.2, C106.2, C107.2, C108.2, C109.2, D101.1 (K), J101.A1 (GND), J101.A12 (GND), J101.B1 (GND), J101.B12 (GND), J102.5, J102.6, J102.7, J102.8, J104.1, R101.2, R107.2, R112.2, R115.2, R117.2, R118.2, R123.1, R124.1, SW101.C, SW101.D, SW102.C, SW102.D, SW103.3, SW103.4, SW103.6 (K), SW104.3, SW104.4, SW104.6 (K), U101.9 (GND), U101.19 (GND), U101.20 (GND), U101.21 (GND), U101.22 (GND), U101.23 (GND), U101.24 (GND), U101.25 (GND), U101.26 (GND), U101.27 (GND), U102.1 (A1), U102.2 (A0), U102.7 (GND), U103.2 (GND), U104.2 (V_{SS}), U105.1 (VSS), U105.7 (~CS)
unnamed: D101.2 (A), R113.2
unnamed: D102.2 (A), R114.2
unnamed: D102.1 (K), D103.2 (A), U104.1 (STAT)
unnamed: D103.1 (K), R115.1
unnamed: J101.A5 (CC1), R124.2
unnamed: J101.B5 (CC2), R123.2
unnamed: C101.1, J101.S1 (SHIELD), R101.1
unnamed: J102.1, J102.2, J102.3, J102.4, R104.1, U102.8 (Vbus), U102.10 (Vin+)
unnamed: J102.9, J102.10, J102.11, J102.12, R104.2, U102.9 (Vin-)
unnamed: J201.A5 (CC1), J202.A5 (CC1)
unnamed: J201.B5 (CC2), J202.B5 (CC2)
unnamed: J201.A6 (D+), J201.B6 (D+), J202.A6 (D+), J202.B6 (D+)
unnamed: J201.A7 (D-), J201.B7 (D-), J202.A7 (D-), J202.B7 (D-)
unnamed: J201.A8 (SBU1), J202.A8 (SBU1)
unnamed: J201.B8 (SBU2), J202.B8 (SBU2)
unnamed: J201.S1 (SHIELD), J202.S1 (SHIELD)
unnamed: J204.3 (D+), J205.3 (D+)
unnamed: J204.2 (D-), J205.2 (D-)
unnamed: J204.6 (Shield), J205.5 (Shield)
unnamed: J207.1, J208.1, J208.2, J208.3, J208.4
unnamed: J207.3, J208.9, J208.10, J208.11, J208.12
unnamed: J209.2, J211.9, J211.10, J211.11, J211.12
unnamed: J210.2, J211.1, J211.2, J211.3, J211.4
unnamed: FB101.2, JP101.1 (A), SW105.2 (B)
unnamed: R119.1, SW103.5 (A)
unnamed: R120.1, SW104.5 (A)
unnamed: R106.2, R107.1, U103.4 (ADJ)
unnamed: R112.1, U104.5 (PROG)

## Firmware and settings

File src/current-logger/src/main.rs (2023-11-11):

use std::{thread, time::Duration};
use esp_idf_hal::{gpio::*, prelude::*, spi, i2c};
use esp_idf_hal::delay::BLOCK;
use esp_idf_hal::peripherals::Peripherals;
use embedded_hal::spi::MODE_0;
use log::*;
use std::time::SystemTime;
use esp_idf_hal::adc::config::Config as AdcConfig;
use esp_idf_hal::adc::AdcChannelDriver;
use esp_idf_hal::adc::AdcDriver;
use esp_idf_hal::adc::Atten11dB;

mod pushswitch;
mod displayctl;
mod currentlogs;
mod wifi;
mod transfer;

use pushswitch::PushSwitch;
use displayctl::{DisplayPanel, LoggingStatus, WifiStatus};
use currentlogs::{CurrentRecord, CurrentLog};
use transfer::Transfer;

#[toml_cfg::toml_config]
pub struct Config {
    #[default("")]
    wifi_ssid: &'static str,
    #[default("")]
    wifi_psk: &'static str,
    #[default("")]
    http_server: &'static str,
}

fn main() -> anyhow::Result<()> {
    esp_idf_sys::link_patches();
    esp_idf_svc::log::EspLogger::initialize_default();

    // Initialize nvs
    unsafe {
        esp_idf_sys::nvs_flash_init();
    }
    // Peripherals Initialize
    let peripherals = Peripherals::take().unwrap();
    
    // Display SPI
    let spi = peripherals.spi2;
    let sclk = peripherals.pins.gpio8;
    let sdo  = peripherals.pins.gpio9;
    let sdi_not_used : Option<Gpio2> = None;
    let cs_not_used : Option<Gpio2> = None;
    let dc = PinDriver::output(peripherals.pins.gpio10)?;
    let rst = PinDriver::output(peripherals.pins.gpio1)?;
    let spi_config = spi::SpiConfig::new().baudrate(4.MHz().into()).data_mode(MODE_0);

    let spi_driver = spi::SpiDriver::new(
        spi,
        sclk,
        sdo,
        sdi_not_used,
        spi::Dma::Disabled,
    ).unwrap();
    
    let spi_device = spi::SpiDeviceDriver::new(spi_driver, cs_not_used, &spi_config)?;
    let mut dp = DisplayPanel::new();
    dp.start(spi_device, dc, rst);

    // Current/Voltage
    let i2c = peripherals.i2c0;
    let scl = peripherals.pins.gpio4;
    let sda = peripherals.pins.gpio3;
    let config = i2c::I2cConfig::new().baudrate(400.kHz().into());
    let mut i2cdrv = i2c::I2cDriver::new(i2c, sda, scl, &config)?;

    // SHUNT_CAL
    let current_lsb = 16.384 / 524_288.0;
    let shunt_cal_val = 13107.2 * current_lsb * 1000_000.0 * 0.010;
    let shunt_cal = shunt_cal_val as u32;
    info!("current_lsb={:?} shunt_cal_val={:?}", current_lsb, shunt_cal_val);
    i2cdrv.write(0x40, &[0x02u8; 1], BLOCK).expect("INA228 I2C Write Error");
    let mut shunt_cal_buf = [0u8; 2];
    shunt_cal_buf[0] = (shunt_cal >> 8) as u8;
    shunt_cal_buf[1] = (shunt_cal & 0xFF) as u8;
    i2cdrv.write(0x40, &shunt_cal_buf, BLOCK)?;

    // PushSW
    let interval_select_pin   = peripherals.pins.gpio20;
    let startstop_pin   = peripherals.pins.gpio21;
    let interval_select_sig   = Box::new(PinDriver::input(interval_select_pin)?);
    let startstop_sig   = Box::new(PinDriver::input(startstop_pin)?);
    let mut psw         = PushSwitch::new();
    psw.start(interval_select_sig, startstop_sig);
    let mut interval_led   = PinDriver::input_output(peripherals.pins.gpio6)?;
    let mut startstop_led   = PinDriver::input_output(peripherals.pins.gpio7)?;
    startstop_led.set_low()?;
    interval_led.set_low()?;

    // Temperature Logs
    let mut clogs = CurrentRecord::new();

    // WiFi
    let wifi_enable : bool;
    let wifi = wifi::wifi_connect(peripherals.modem, CONFIG.wifi_ssid, CONFIG.wifi_psk);
    match wifi {
        Ok(_) => { wifi_enable = true; },
        Err(e) => { info!("{:?}", e); wifi_enable = false }
    }
    let mut txd =  Transfer::new(CONFIG.http_server.to_string());
    txd.start()?;
    
    // ADC GPIO0
    let mut adc = AdcDriver::new(peripherals.adc1, &AdcConfig::new().calibration(true))?;
    let mut adc_pin: esp_idf_hal::adc::AdcChannelDriver<'_, Gpio0, Atten11dB<_>> =
        AdcChannelDriver::new(peripherals.pins.gpio0)?;

    // loop
    let mut measurement_count : u32 = 0;
    let mut logging_start = false;
    let mut measuring_interval : u32 = 4;    // 4ms interval time when it starts
    dp.set_interval(measuring_interval+1);
    let mut start_logging_time = SystemTime::now();
    let mut next_time = start_logging_time.checked_add(Duration::from_millis(measuring_interval as u64)).expect("no next_time");
    let mut measurement_light = false;
    loop {
        thread::sleep(Duration::from_millis(1));

        let interval_select_btn = psw.get_gpio_state(20);
        let start_stop_btn = psw.get_gpio_state(21);
        if start_stop_btn == true {
            if logging_start == true {
                // to Stop
                logging_start = false;
                // clogs.dump();
                // clogs.clear();
            }
            else {
                // to Start
                logging_start = true;
                measurement_count = 0;
                info!("Logging and Sending Start..");
                clogs.clear();
                start_logging_time = SystemTime::now();
            }
        }
        if interval_select_btn == true {
            measuring_interval = match measuring_interval {
                4   => 9,
                9   => 49,
                49  => 99,
                99  => 499,
                499 => 999,
                _ => 4,
            };
            dp.set_interval(measuring_interval+1);
            measurement_light = false;
            measurement_count = 0;
            start_logging_time = SystemTime::now();
            next_time = start_logging_time.checked_add(Duration::from_millis(measuring_interval as u64)).expect("no next_time");
        }

        if wifi_enable == false{
            dp.set_wifi_status(WifiStatus::Disconnected);
        }
        else {
            dp.set_wifi_status(WifiStatus::Connected);
        }

        if logging_start == true {
            startstop_led.set_high()?;
            dp.set_current_status(LoggingStatus::Start);
        }
        else {
            startstop_led.set_low()?;
            dp.set_current_status(LoggingStatus::Stop);
        }


        let intime = next_time.duration_since(SystemTime::now());
        match intime {
            Ok(_v) => { continue },
            Err(_e) => { },
        }
        measurement_count += 1;
        next_time = start_logging_time.checked_add(Duration::from_millis((measuring_interval * measurement_count) as u64)).expect("no next_time");
//        let duration = SystemTime::now();

        if measurement_light == false {
            interval_led.set_high()?;
            measurement_light = true;
        }
        else {
            interval_led.set_low()?;
            measurement_light = false;
        }

       // Read Current/Voltage
        let mut vbus_buf  = [0u8; 3];
        let mut data = CurrentLog::default();
        // Timestamp
        data.clock = start_logging_time.elapsed().unwrap().as_millis() as u32;

        i2cdrv.write(0x40, &[0x05u8; 1], BLOCK)?;
        match i2cdrv.read(0x40, &mut vbus_buf, BLOCK){
            Ok(_v) => {
                // info!("vbus={:?}", vbus_buf);
                let vbus = ((((vbus_buf[0] as u32) << 16 | (vbus_buf[1] as u32) << 8 | (vbus_buf[2] as u32)) >> 4) as f32 * 193.3125) / 1000_000.0;
                data.voltage = vbus; // V
            },
            Err(e) => {
                info!("{:?}", e);
                dp.set_err_message(format!("{:?}", e));
            }
        }
        let mut curt_buf  = [0u8; 3];
        i2cdrv.write(0x40, &[0x07u8; 1], BLOCK)?;
        match i2cdrv.read(0x40, &mut curt_buf, BLOCK) {
            Ok(_v) => {
                let current_reg : f32;
                if curt_buf[0] & 0x80 == 0x80 {
                    current_reg = (0x100000 - (((curt_buf[0] as u32) << 16 | (curt_buf[1] as u32) << 8 | (curt_buf[2] as u32)) >> 4)) as f32 * -1.0;
                }
                else {
                    current_reg = (((curt_buf[0] as u32) << 16 | (curt_buf[1] as u32) << 8 | (curt_buf[2] as u32)) >> 4) as f32;
                }
                let current = current_lsb * current_reg;
                data.current = current;   // A
                // info!("curt={:?} {:?}A", curt_buf, data.current);
            },
            Err(e) => {
                info!("{:?}", e);
                dp.set_err_message(format!("{:?}", e));
            }
        }
        let mut power_buf = [0u8; 3];
        i2cdrv.write(0x40, &[0x08u8; 1], BLOCK)?;
        match i2cdrv.read(0x40, &mut power_buf, BLOCK) {
            Ok(_v) => {
                // info!("power={:?}", power_buf);
                let power_reg = ((power_buf[0] as u32) << 16 | (power_buf[1] as u32) << 8 | (power_buf[2] as u32)) as f32;
                let power = 3.2 * current_lsb * power_reg;        
                data.power = power;   // W
            },
            Err(e) => {
                info!("{:?}", e);
                dp.set_err_message(format!("{:?}", e));
            }
        }
        // battery voltage 
        data.battery =  adc.read(&mut adc_pin).unwrap() as f32 * 2.0 / 1000.0;
        dp.set_battery(data.battery);
        dp.set_voltage(data.voltage, data.current, data.power);
        if logging_start {
            clogs.record(data);
        }
        let current_record = clogs.get_size();
        if current_record >= 4095 {
            logging_start = false;  // Auto stop logging if buffer is full.
        }
        dp.set_buffer_watermark((current_record as u32) * 100 / 4095);

        if wifi_enable == true && current_record > 0 {
            let logs = clogs.get_all_data();
            let txcount = txd.set_transfer_data(logs);
            if txcount > 0 {
                clogs.remove_data(txcount);
            }
        }
//        info!("duration = {:?}", duration.elapsed().unwrap().as_millis());
    }
}

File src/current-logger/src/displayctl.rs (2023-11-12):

use log::*;
use std::{thread, time::Duration, sync::Arc, sync::Mutex};
use esp_idf_hal::{gpio::*, spi, delay::FreeRtos};
use ssd1331::{DisplayRotation, Ssd1331};
use embedded_graphics::{
    mono_font::{ascii::FONT_10X20, ascii::FONT_5X8, ascii::FONT_6X12, MonoTextStyle},
    image::Image,
    pixelcolor::{Rgb565},
    text::{Text},
    geometry::Point,
    primitives::{
        Circle, Line, Triangle, PrimitiveStyle,
    },
    prelude::*,
};
use tinybmp::Bmp;

pub enum LoggingStatus {
    Start,
    Stop,
}

pub enum WifiStatus {
    Connected,
    Disconnected,
}

type SPI<'d> = esp_idf_hal::spi::SpiDeviceDriver<'static, spi::SpiDriver<'static>>;
type DC<'d> = esp_idf_hal::gpio::PinDriver<'static, Gpio10, esp_idf_hal::gpio::Output>;
type RST<'d> = esp_idf_hal::gpio::PinDriver<'static, Gpio1, esp_idf_hal::gpio::Output>;

struct DisplayText {
    voltage: f32,
    current: f32,
    power: f32,
    interval: u32,
    message: String,
    battery: f32,
    status: LoggingStatus,
    wifi: WifiStatus,
    buffer_water_mark: u32,
}

pub struct DisplayPanel {
    txt: Arc<Mutex<DisplayText>>
}

impl DisplayPanel {

    pub fn new() -> DisplayPanel {
        DisplayPanel { txt: Arc::new(Mutex::new(
            DisplayText {voltage: 0.0,
                         message: "".to_string(),
                         current: 0.0,
                         power: 0.0,
                         interval: 0,
                         battery: 0.0,
                         status: LoggingStatus::Stop,
                         wifi: WifiStatus::Disconnected,
                         buffer_water_mark: 0,
                     })) }
    }

    pub fn start(&mut self,
        spi : SPI, dc: DC, mut rst : RST)
    {
        let txt = self.txt.clone();
        let _th = thread::spawn(move || {
            info!("Start Display Thread.");
            let mut delay = FreeRtos;
            let mut display = Ssd1331::new(spi, dc, DisplayRotation::Rotate180);
            let _ = display.reset(&mut rst, &mut delay);
            let _ = display.init();
            display.clear();
            let style = MonoTextStyle::new(&FONT_10X20, Rgb565::WHITE);
            let middle_style_white = MonoTextStyle::new(&FONT_6X12, Rgb565::WHITE);
            let middle_style_red = MonoTextStyle::new(&FONT_6X12, Rgb565::RED);
            let small_style_white = MonoTextStyle::new(&FONT_5X8, Rgb565::WHITE);
            let wifibmp = Bmp::from_slice(include_bytes!("./img/wifirev.bmp")).unwrap();
            let wifi_img: Image<Bmp<Rgb565>> = Image::new(&wifibmp, Point::new(76,1));
            let fill = PrimitiveStyle::with_fill(Rgb565::YELLOW);

            // Battery BMP
            let bat_x = 81;
            let bat_y = 33;
            let bat0 = Bmp::from_slice(include_bytes!("./img/battery-0.bmp")).unwrap();
            let bat0_img: Image<Bmp<Rgb565>> = Image::new(&bat0, Point::new(bat_x, bat_y));
            let bat20 = Bmp::from_slice(include_bytes!("./img/battery-20.bmp")).unwrap();
            let bat20_img: Image<Bmp<Rgb565>> = Image::new(&bat20, Point::new(bat_x, bat_y));
            let bat40 = Bmp::from_slice(include_bytes!("./img/battery-40.bmp")).unwrap();
            let bat40_img: Image<Bmp<Rgb565>> = Image::new(&bat40, Point::new(bat_x, bat_y));
            let bat60 = Bmp::from_slice(include_bytes!("./img/battery-60.bmp")).unwrap();
            let bat60_img: Image<Bmp<Rgb565>> = Image::new(&bat60, Point::new(bat_x, bat_y));
            let bat80 = Bmp::from_slice(include_bytes!("./img/battery-80.bmp")).unwrap();
            let bat80_img: Image<Bmp<Rgb565>> = Image::new(&bat80, Point::new(bat_x, bat_y));
            let bat100 = Bmp::from_slice(include_bytes!("./img/battery-100.bmp")).unwrap();
            let bat100_img: Image<Bmp<Rgb565>> = Image::new(&bat100, Point::new(bat_x, bat_y));
            let usbpwr = Bmp::from_slice(include_bytes!("./img/usb-power.bmp")).unwrap();
            let usbpwr_img: Image<Bmp<Rgb565>> = Image::new(&usbpwr, Point::new(bat_x, bat_y));

            // Number BMP
            let n0 = Bmp::from_slice(include_bytes!("./img/n0.bmp")).unwrap();
            let n0_img: Image<Bmp<Rgb565>> = Image::new(&n0, Point::zero());
            let n1 = Bmp::from_slice(include_bytes!("./img/n1.bmp")).unwrap();
            let n1_img: Image<Bmp<Rgb565>> = Image::new(&n1, Point::zero());
            let n2 = Bmp::from_slice(include_bytes!("./img/n2.bmp")).unwrap();
            let n2_img: Image<Bmp<Rgb565>> = Image::new(&n2, Point::zero());
            let n3 = Bmp::from_slice(include_bytes!("./img/n3.bmp")).unwrap();
            let n3_img: Image<Bmp<Rgb565>> = Image::new(&n3, Point::zero());
            let n4 = Bmp::from_slice(include_bytes!("./img/n4.bmp")).unwrap();
            let n4_img: Image<Bmp<Rgb565>> = Image::new(&n4, Point::zero());
            let n5 = Bmp::from_slice(include_bytes!("./img/n5.bmp")).unwrap();
            let n5_img: Image<Bmp<Rgb565>> = Image::new(&n5, Point::zero());
            let n6 = Bmp::from_slice(include_bytes!("./img/n6.bmp")).unwrap();
            let n6_img: Image<Bmp<Rgb565>> = Image::new(&n6, Point::zero());
            let n7 = Bmp::from_slice(include_bytes!("./img/n7.bmp")).unwrap();
            let n7_img: Image<Bmp<Rgb565>> = Image::new(&n7, Point::zero());
            let n8 = Bmp::from_slice(include_bytes!("./img/n8.bmp")).unwrap();
            let n8_img: Image<Bmp<Rgb565>> = Image::new(&n8, Point::zero());
            let n9 = Bmp::from_slice(include_bytes!("./img/n9.bmp")).unwrap();
            let n9_img: Image<Bmp<Rgb565>> = Image::new(&n9, Point::zero());
            let vv = Bmp::from_slice(include_bytes!("./img/v.bmp")).unwrap();
            let vv_img: Image<Bmp<Rgb565>> = Image::new(&vv, Point::new(68, 0));
            let dot = Bmp::from_slice(include_bytes!("./img/dot.bmp")).unwrap();
            let dot_img: Image<Bmp<Rgb565>> = Image::new(&dot, Point::zero());
            let minus = Bmp::from_slice(include_bytes!("./img/minus.bmp")).unwrap();
            let minus_img: Image<Bmp<Rgb565>> = Image::new(&minus, Point::zero());
            let mut digit_img = n0_img.translate(Point::new(0,0));
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

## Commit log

2023-11-11 Add hardware data
    [Adopter-Battery-Upper-v10.stl, Adopter-Terminal-Upper-v12.stl, Adopter-TypeAB-Upper-v10.stl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]
2023-11-12 Update PCB data
2023-11-12 Battery voltage should be average.
